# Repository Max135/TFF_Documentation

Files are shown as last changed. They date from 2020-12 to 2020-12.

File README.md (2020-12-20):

# Documentation TFF Smart Fishing Sensor
<p align="center">
    
</p>
Ici se trouve tous les fichiers et documents reliés avec le TFF Smart Fishing Sensor.

## Liens externes
* [Page GitHub du site web](https://github.com/Max135/TFF)
* [Ancien site web](http://tff.sexy)
* [Micro-contrôleur](https://www.adafruit.com/product/4516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)

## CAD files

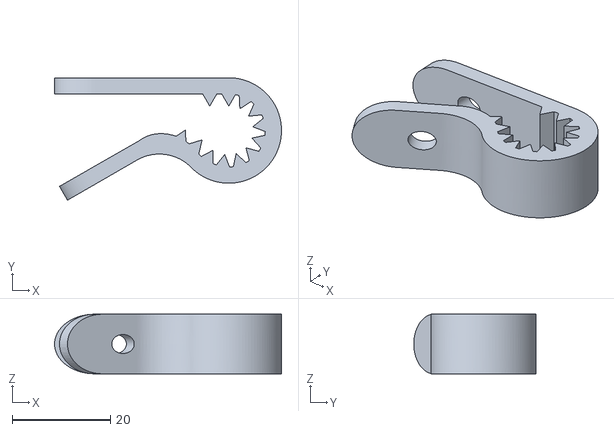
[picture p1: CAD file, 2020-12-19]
Microcontroller/Microcontroller Case/TFF_Clamp.stl
46.2 x 24.9 x 12.1

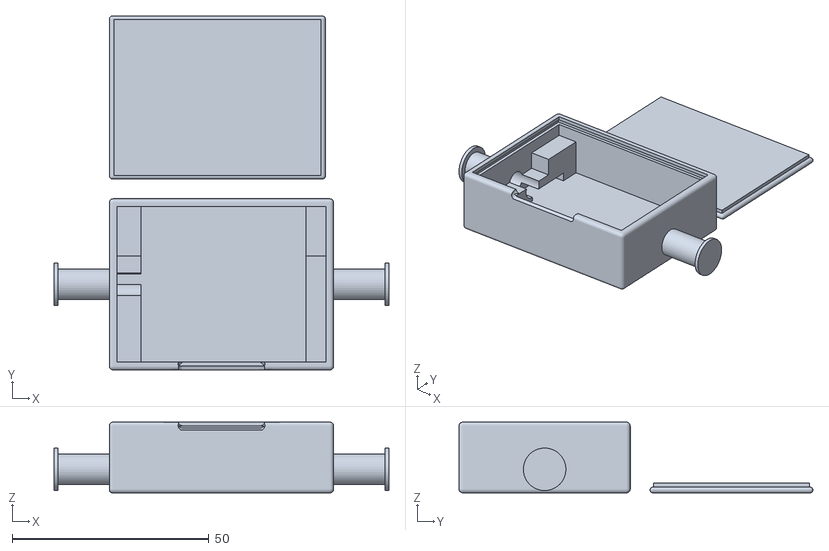
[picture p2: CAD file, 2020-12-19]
Microcontroller/Microcontroller Case/Microcontroller Case v12 + Lid.stl
85.0 x 89.9 x 18.0

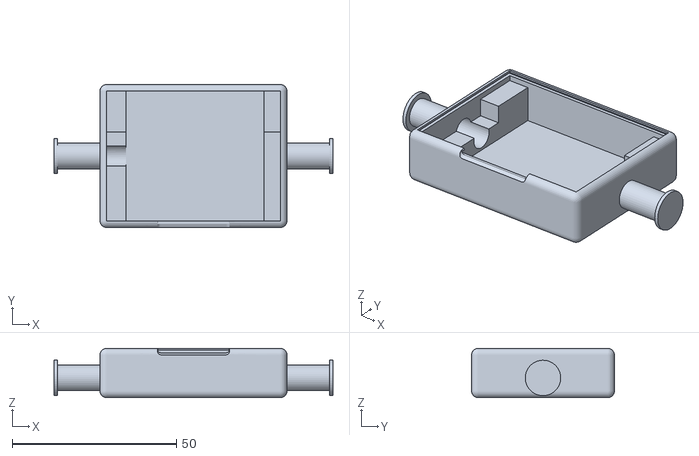
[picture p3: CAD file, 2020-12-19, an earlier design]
Microcontroller/Microcontroller Case/Microcontroller Case v10.stl
85.0 x 43.5 x 15.0

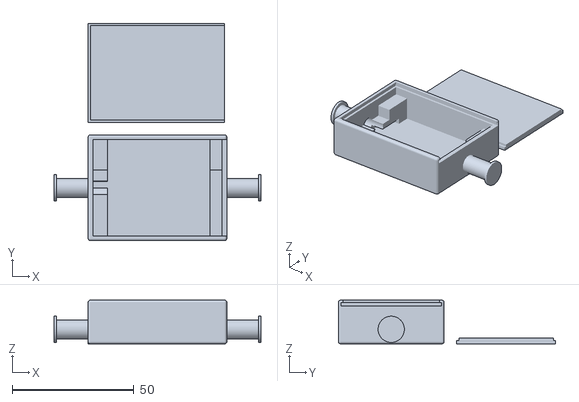
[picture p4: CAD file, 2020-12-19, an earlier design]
Microcontroller/Microcontroller Case/Microcontroller Case v16.stl
85.0 x 89.3 x 18.0

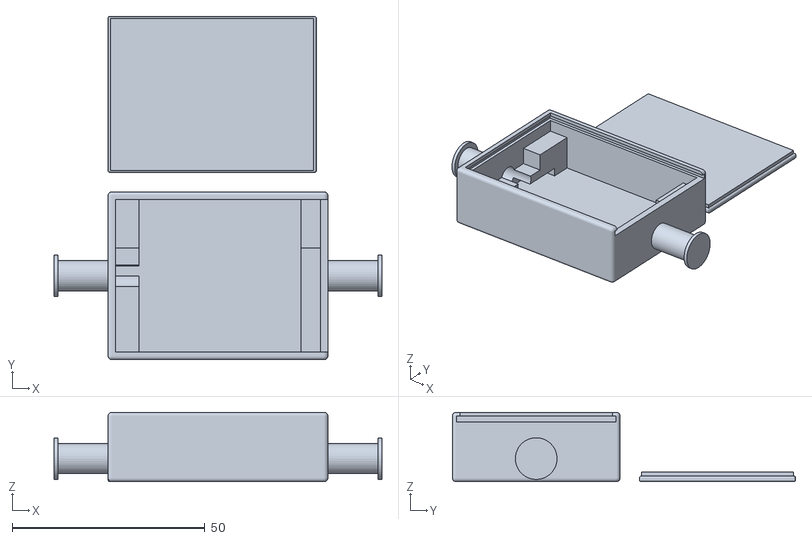
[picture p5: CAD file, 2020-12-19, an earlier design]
Microcontroller/Microcontroller Case/Microcontroller Case v14.stl
85.0 x 89.0 x 18.0

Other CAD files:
Microcontroller/Microcontroller Case/Microcontroller Case v18.stl
Microcontroller/Microcontroller Case/Microcontroller Case v17.stl

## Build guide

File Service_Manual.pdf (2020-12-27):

# Three Fishermen Friends

## Cégep de Sorel-Tracy

# Manuel de service client

## TFF Smart Fishing sensor™

Dernière modification: 19 Décembre 2020

Par: Mickael Salvas, Xavier Loiselle et Maxime Desmarais

Ce document a pour but d’expliquer les détails plus techniques du projet sous trois parties: soit le micro contrôleur, l’application mobile et le site web. Pour tous les documents qui ne se trouve pas dans celui-ci veuillez visiter le GitHub de documentation avec le lien suivant: https://github.com/Max135/TFF_Documentation

## Table des matières

## Three Fishermen Friends ______________________________1

### Manuel de Service Client ________________________________________1

TFF Smart Fishing Sensor™______________________________________________1

### Matériel ________________________________________________________3

Boîtier__________________________________________________________________3 Design du Boitier________________________________________________________3 Composantes Utilisés ___________________________________________________4 Algorithme Micro Contrôleur______________________________________________4 Diagramme Fonctionnel Micro Contrôleur__________________________________5

### Application Mobile ______________________________________________6

Fonctionnement_________________________________________________________6 Diagramme Fonctionnel Application_______________________________________7

### Site Web _______________________________________________________8

Fonctionnement_________________________________________________________8 Diagramme Fonctionnel Site______________________________________________9 Algorithme Hotspot_____________________________________________________10

### Debug ________________________________________________________10

Micro Contrôleur Bricked _______________________________________________10 Aucune Détection de Touches ___________________________________________11

### DIY___________________________________________________________11

## Matériel

## Boîtier

Le boîtier du micro contrôleur et de la batterie a été conçu avec Fusion360.

Le trancheur utilisé pour imprimer le boitier est Ultimaker Cura avec les paramètres suivant:

- Layer height: 0.12mm
- Infill: 100%
- Support: On
- Adhesion: On
L’imprimante utilisée pour imprimer le boitier est une Creality Ender 3 Pro avec du filament PLA noir avec les paramètres suivant:
- Extruder temperature: 200°C
- Bed temperature: 60°C

## Design du boitier

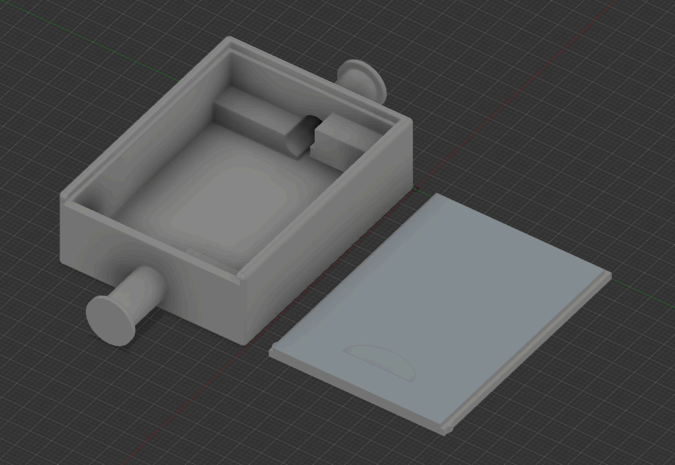
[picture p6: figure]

## Composantes utilisés

Le micro contrôleur utilisé est un Adafruit Feather nRF52840 Sense avec un processeur Nordic nRF52840 Bluetooth LE processor. Le contrôleur comprend les composante suivantes:

- Accéléromètre et gyroscope LSM6DS33
- BME 280
- Microphone PDM
- Détecteur d'humidité SHT
- Capteur de proximité, couleur, lumière et geste APDS9960

De plus, un capteur de vibration Adafruit Industries LLC 1766 (fast) est utilisé.

Le capteur de vibration est connecté au micro contrôleur grâce au pin 10 et 13 de celui-ci.

Le tout est alimenté par une batterie li-po 503035 500mAh.

## Algorithme micro contrôleur

- Le micro contrôleur tente de se connecter à un appareil grâce au Bluetooth
- Une fois une connection établie, le micro contrôleur lit les données de ses sensors à un intervalle de temps donné (actuellement au 5 secondes)
- Le micro contrôleur envoie les données recueillies à l’appareil mobile connecté
- Si une vibration ou une grande accélération est détectée, le micro contrôleur envoi un signal à l'appareil connecté

## Diagramme Fonctionnel micro contrôleur

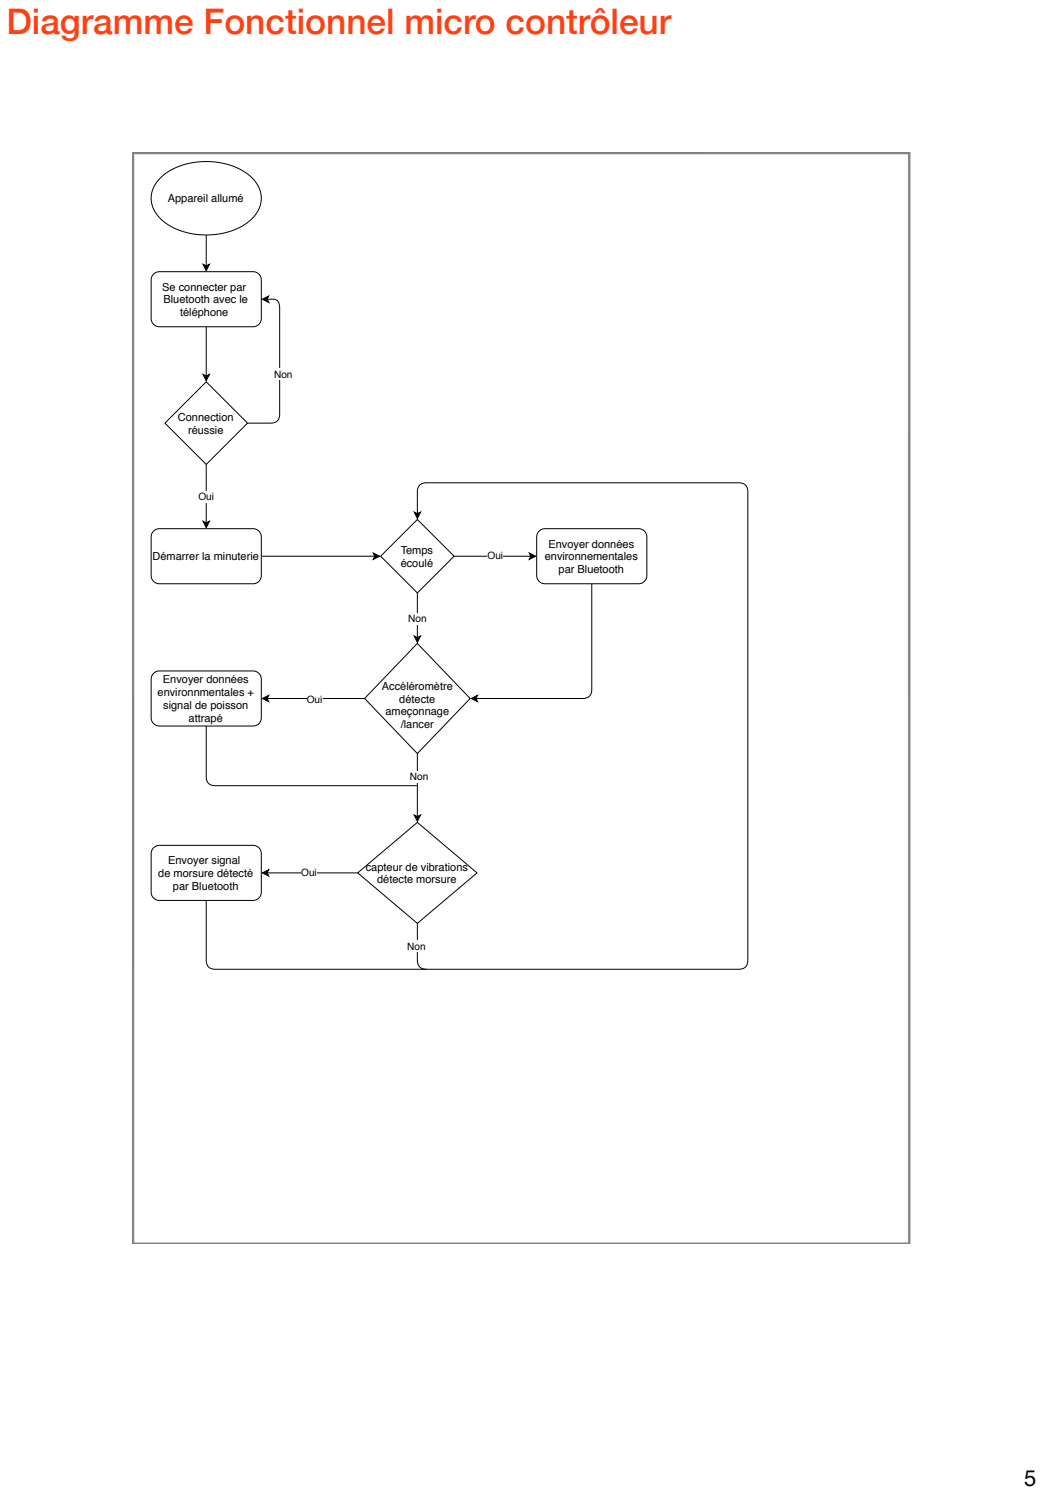
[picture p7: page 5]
Oui; Non; Accéléromètre détecte ameçonnage /lancer; Connection réussie; Démarrer la minuterie; Temps écoulé; Envoyer données environnementales par Bluetooth; Appareil allumé

Se connecter par
Bluetooth avec le
téléphone

Envoyer données
environnmentales +
signal de poisson
attrapé

Envoyer signal
de morsure détecté
par Bluetooth

capteur de vibrations
détecte morsure

## Application mobile

Voici la section consacrée à l’application mobile, incluant son fonctionnement et son diagramme fonctionnel.

## Fonctionnement

- Pour le bon fonctionnement de l’application, il faut que l’application aie accès au Bluetooth, au données GPS, ainsi qu’à l’appareil photo.
- L’application fonctionne en se connectant avec un utilisateur créé sur notre site web (anciennement tff.sexy), en faisant une requête sur notre serveur web pour vérifier l’authentification.
- Lorsque l’utilisateur va se connecter, l’application mobile va faire une requête sur notre serveur web pour obtenir les données de vent selon la position géo-localisée du cellulaire.
- Après la connexion, l’application va commencer à chercher les appareils étant rattachés à un certain UUID (spécifié dans le code de l’application mobile ainsi que le code du micro contrôleur).
- Lorsque l’application va trouver un appareil, elle va tout de suite s’y connecter et commencer à écouter pour recevoir les données de l’appareil connecté.
- Par après, l’application mobile va afficher les données qu’elles va recevoir du micro contrôleur dans les différentes pages (Données météo / Données pêche).
- Ensuite, lorsque l’utilisateur commence un voyage de pêche, l’application mobile envoie une requête à notre serveur web pour lui indiquer le commencement du voyage, et obtenir son identifiant.
- L’affichage des données de pêche est simplement une incrémentation des données reçues par le micro contrôleur.
- Lorsque l’on ajoute une nouvelle capture, l’application envoie à notre serveur web les informations du poisson, ainsi que la photo (ces données sont optionnelles).
- Lors de la fin d’un voyage de pêche, l’application envoie au serveur les données qu’elle à recueillie (météo, données de pêche).

## Diagramme fonctionnel application

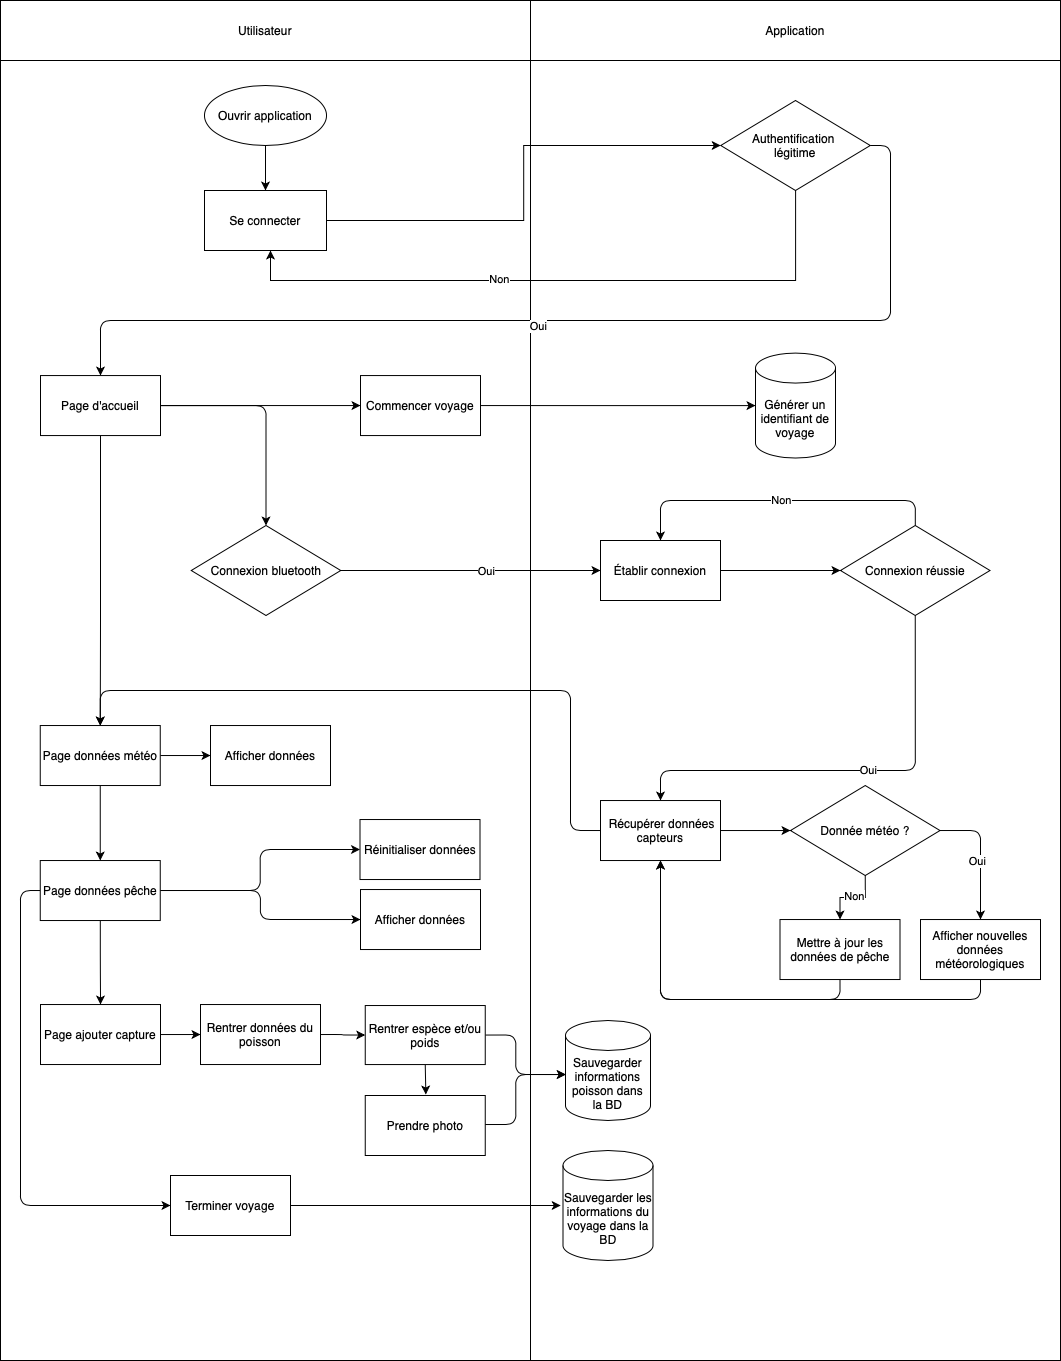
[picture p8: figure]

## Site Web

Le site est fait avec du PHP avec l’aide du framework Zephyrus, Pug est utilisé comme moteur de visualisation et la base de donnée est en mySQL. La carte affichée dans le site est avec Mapbox GL JS (https://docs.mapbox.com/mapbox-gl-js/api/). Tous le code en lien avec le site web peut être trouver dans le GitHub suivant : https://github.com/Max135/TFF

## Fonctionnement

L’utilisateur arrive sur la page index qui donne quelques petites informations sur le produit. Puis avec la navigation à droite, l’utilisateur peut se connecter ou créer un compte.

Après l’authentification avec le courriel et le mot de passe, l’utilisateur est redirigé vers la page avec sa carte qui indique l’emplacement de tous ses point de pêche (Hotspot). L’utilisateur peut appuyer sur un point pour consulter les statistiques et quelques informations du point. Les informations afficher sont le nombre total de poissons attrapés, le nombre total de morsures détectés par le micro contrôleur et le nombre total de ferrages. Une liste de toutes les pressions moyennes pour tous les voyages de pêche dans ce point est affiché. Puis, un icône de vent, avec la vitesse totale de ceux-ci et un icône de caméra seront affiché à l’écran. L’icône de vent apporte sur une page qui indique la moyenne des vitesse de vent ainsi que le minimum et maximum de ceux-ci qui sont affichés avec l'aide d’un graphique. L’icône de caméra redirige vers une page qui affiche tous les photos de poisson prisent avec l’application mobile mentionnée auparavant.

La section permission du site est l’endroit dédié pour faire la gestion du partage des points de pêche, qui ne sont pas partagés par défaut.

La section ami du site permet d’ajouter ou d’enlever des amis. Un ami peut être ajouté avec le courriel de celui-ci. Puis l’utilisateur peut visiter la carte des tous ses amis.

## Diagramme fonctionnel site

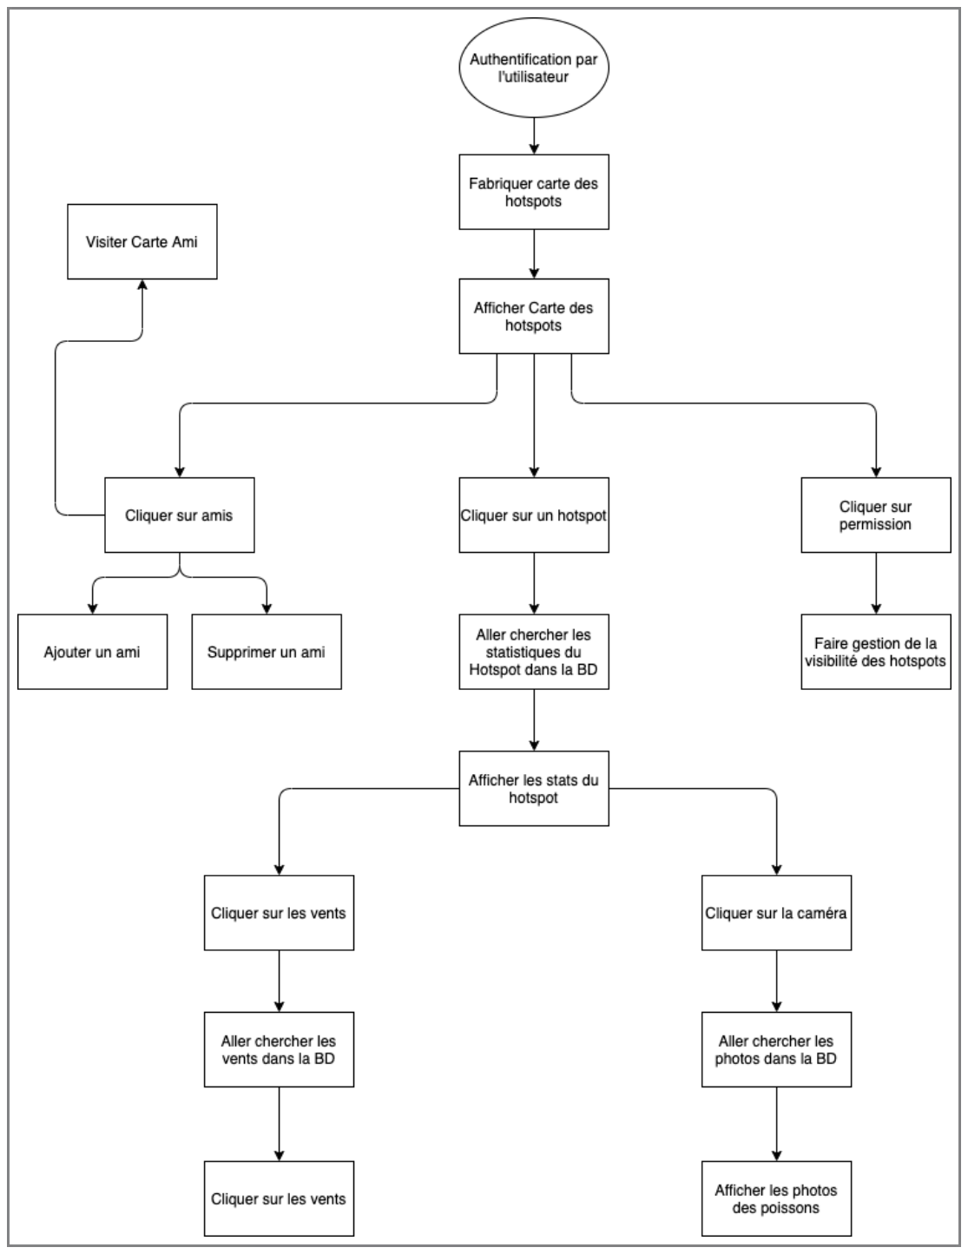
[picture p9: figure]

## Algorithme hotspot

L’algorithme de création de hotspot suit la logique suivante:

- Lors de l’insertion d’un poisson dans la base de donnée (une prise), on vérifie si les coordonnées de la prise sont contenues à l’intérieur d’un hotspot existant.
- Si la prise est contenue dans un hotspot existant, on l’ajoute à ce hotspot, sinon, on vérifie si les coordonnées de deux poissons attrapés par l’utilisateur sont à moins de 200 mètres (Peut être changé facilement)
- Si deux poissons sont assez près l’un de l’autre, on crée un nouveau hotspot qui pourra par la suite contenir d’autres prises, sinon, le poisson est laissé dans le limbo de la base de donnée pour ne plus jamais être revu

## Debug

## Micro contrôleur bricked

Si vous ne recevez plus de signal de votre TFF Smart Fishing sensor™ ou que vous n’êtes plus capable de vous connecter à celui-ci,

1. Retirez le couvercle du boitier
2. Si la DEL multicolore ne change pas de couleur périodiquement suivez les instructions suivante
3. Sortez le micro contrôleur pour pouvoir brancher un câble micro-usb dans son port micro-usb
4. Appuyez rapidement deux fois sur le bouton « Reset », la DEL multicolore devrais maintenant être verte

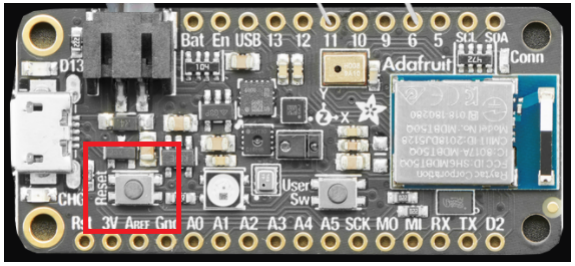
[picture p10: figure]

5. Branchez maintenant le câble micro usb entre votre ordinateur et le micro contrôleur et flashez le avec le code fourni sur git hub avec Arduino IDE
6. Déconnectez le câble micro usb de votre micro contrôleur et rangez le dans le boitier
7. Voilà votre TFF Smart Fishing sensor™ devrais maintenant fonctionner comme neuf!

## Aucune détection de touches

Si votre TFF Smart Fishing sensor™ ne détecte plus les touches alors que vous êtes sûr de les sentir

1. Vérifiez si les fils connectés à votre capteur de vibration ne sont pas coupés
2. Vérifiez si le capteur de vibration est bien connecté aux fils
3. Si votre problème n’est toujours pas réglé, ouvrez le boîtier
4. Vérifiez que les soudures sur le micro contrôleur tiennent toujours
5. Si les soudures sont encore bonnes, remplacez le capteur de vibration, sinon, ressoudez les fils qui ont perdus contact
6. Vous êtes maintenant prêt à retourner pêcher dans vos hotspot favoris!

## DIY

1. Acheter tout le materiel nécessaire
2. Imprimer le boitier
3. Télécharger le code de l’application mobile à partir du Github
4. Installer l’application mobile sur un appareil Apple
5. Connecter la batterie avec le contrôleur
6. Télécharger le script du contrôleur à partir du GitHub
7. Déployer le script sur le micro contrôleur
8. Insérer le contrôleur et la batterie dans le boitier
9. Fixer le boitier sur la canne à pêche
10. Fixer le capteur de vibration plus haut sur la canne à pêche
11. Connecter le capteur dans les pines 10 et 13 du contrôleur
12. Se connecter au contrôleur avec l’application mobile
13. Pêcher !

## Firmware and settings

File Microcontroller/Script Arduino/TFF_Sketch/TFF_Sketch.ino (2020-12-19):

#include <TimedAction.h>
#include <Adafruit_NeoPixel.h>

#include <bluefruit.h>
#include <Adafruit_LittleFS.h>
#include <InternalFileSystem.h>

#include <Adafruit_BMP280.h>
#include <Adafruit_LSM6DS33.h> 
#include <Adafruit_SHT31.h> 
#include <Adafruit_Sensor.h> 

#define RGB_LED_PIN     8
#define LED_COUNT       1
#define PIN_OUT         10
#define PIN_IN          13
#define MIN             -15.5
#define MAX             15.5

#define MAX_TIME_LAST_HOOK 5000

void randomColor();
void setupRGB();
void setupVibrationSensor();
void vibrationDetected();
void getTemperature();
void getPressure();
void getCellphoneData();
void getHumidity();
void getHook();
void getVibration();
void getUserActions();

void sendData();
bool isAccelInTreshold(float, float, float);
void getHookDetected();

BLEDfu  bledfu;  // OTA DFU service
BLEDis  bledis;  // device information
BLEUart bleuart; // uart over ble
BLEBas  blebas;  // battery

Adafruit_BMP280 bmp280; // temperature, barometric pressure
Adafruit_LSM6DS33 lsm6ds33; // accelerometer, gyroscope
Adafruit_SHT31 sht30; // humidity


float temperature, pressure, altitude; 
float accel_x, accel_y, accel_z;
float gyro_x, gyro_y, gyro_z;
float humidity;
String hookDetected;

short sampleBuffer[256]; // buffer to read samples into, each sample is 16-bits 
volatile int samplesRead; // number of samples read

Adafruit_NeoPixel strip(LED_COUNT, RGB_LED_PIN, NEO_GRB + NEO_KHZ800);
boolean vibrationLastClock = false;
boolean hookDetectedLastClock = false;
unsigned long timeLastHook = millis();

TimedAction sendDataThread = TimedAction(5000, sendData);
TimedAction checkHookThread = TimedAction(100, getHookDetected);
TimedAction vibrationThread = TimedAction(1000, getUserActions);
//TimedAction tempThread = TimedAction(5000, getTemperature);
//TimedAction pressureThread = TimedAction(5000, getPressure);
//TimedAction humidityThread = TimedAction(5000, getHumidity);
TimedAction dataThread = TimedAction(10, getCellphoneData);

void setup() {
  Serial.begin(115200);
  setupSensors();
  setupRGB();
  setupVibrationSensor();

  setupBluefruit();
  startBledfu();
  setupBledis();
  startBleuart();
  setupBlebas();
  
  startAdv();

}

void loop() {
  sendDataThread.check();
  checkHookThread.check();
  vibrationThread.check();
//  randomColor();
}

void setupSensors() {
  bmp280.begin();
  lsm6ds33.begin_I2C();
  sht30.begin();
}

void setupBluefruit() {
  Bluefruit.autoConnLed(true);
  Bluefruit.configPrphBandwidth(BANDWIDTH_MAX);
  Bluefruit.begin();
  Bluefruit.setTxPower(4);
  Bluefruit.setName("TFF Smart Fishing");
  
  Bluefruit.Periph.setConnectCallback(connect_callback);
  Bluefruit.Periph.setDisconnectCallback(disconnect_callback);
}

void startBledfu() {
  bledfu.begin();
}

void setupBledis() {
  bledis.setManufacturer("Three Fisherman Friends");
  bledis.setModel("TFF SF-1.0");
  bledis.begin();
}

void startBleuart() {
  bleuart.begin();
}

void setupBlebas() {
  blebas.begin();
  blebas.write(100);
}

void startAdv(void) {
  Bluefruit.Advertising.addFlags(BLE_GAP_ADV_FLAGS_LE_ONLY_GENERAL_DISC_MODE);
  Bluefruit.Advertising.addTxPower();

  Bluefruit.Advertising.addService(bleuart);

  Bluefruit.ScanResponse.addName();

  Bluefruit.Advertising.restartOnDisconnect(true);
  Bluefruit.Advertising.setInterval(32, 244);
  Bluefruit.Advertising.setFastTimeout(30);
  Bluefruit.Advertising.start(0);
}

void sendData() {
  getTemperature();
  getHumidity();
  getPressure();
}

void getUserActions() {
  getHook();
  getVibration();
  randomColor();
}

void getVibration() {
  digitalWrite(PIN_OUT, HIGH);
  if(vibrationLastClock) {
    Serial.println("Vibration detected");
    char buf[128];
    int ret = snprintf(buf, sizeof(buf), "%s", "true <vibration>");
    bleuart.write(buf, ret);
    vibrationLastClock = false;
  }
}

void getHook() {
  Serial.println(hookDetectedLastClock);
  if (hookDetectedLastClock) {
    char buf[128];
    int ret = snprintf(buf, sizeof(buf), "%s", "true <hook>");
    Serial.println(hookDetected);
    bleuart.write(buf, ret);
    hookDetectedLastClock = false;
  }
}

void getHookDetected() {
  if(millis() - timeLastHook > MAX_TIME_LAST_HOOK) {
    sensors_event_t accel;
    sensors_event_t gyro;
    sensors_event_t temp; //temp needed by .getEvent for some reason
    lsm6ds33.getEvent(&accel, &gyro, &temp); 
    accel_x = accel.acceleration.x;
    accel_y = accel.acceleration.y; 
    accel_z = accel.acceleration.z; 
    gyro_x = gyro.gyro.x;
    gyro_y = gyro.gyro.y;
    gyro_z = gyro.gyro.z;
    if (isAccelInTreshold(accel_x, accel_y, accel_z)) {
      Serial.println();
      Serial.print("Throw or hook : ");
      Serial.print("X ");
      Serial.print(accel_x);
      Serial.print(" ");
      Serial.print("Y ");
      Serial.print(accel_y); 
      Serial.print(" ");
      Serial.print("Z ");
      Serial.print(accel_z);
      hookDetectedLastClock = true;
      timeLastHook = millis();
    }
  }
}

bool isAccelInTreshold(float x, float y, float z) {
    return (x < MIN || x > MAX || y < MIN || y > MAX || z < MIN || z > MAX);
}

void getTemperature() {
  char buf[128];
  temperature = bmp280.readTemperature();
  int ret = snprintf(buf, sizeof(buf), "%f%s", temperature, "<temperature>");
  Serial.println();
  Serial.printf("Temperature: %f\n", temperature);
  bleuart.write(buf, ret);
  
}

void getHumidity() {
  char buf[128];
  humidity = sht30.readHumidity();
  int ret = snprintf(buf, sizeof(buf), "%f%s", humidity, "<humidity>");
  Serial.printf("Humidity: %f\n", humidity);
  bleuart.write(buf, ret);
}

void getPressure() {
  char buf[128];
  pressure = bmp280.readPressure() / 1000; // divided by 1000 to convert the pressure from pascals to kiloPascals (kPa)
  int ret = snprintf(buf, sizeof(buf), "%f%s", pressure, "<pressure>");
  Serial.printf("Pressure: %f\n", pressure);
  bleuart.write(buf, ret);
}

void getCellphoneData() {
    while ( bleuart.available() )
    {
      uint8_t ch;
      ch = (uint8_t) bleuart.read();
      Serial.write(ch);
    }
}

void connect_callback(uint16_t conn_handle) {
  // Get the reference to current connection
  BLEConnection* connection = Bluefruit.Connection(conn_handle);

  char central_name[32] = { 0 };
  connection->getPeerName(central_name, sizeof(central_name));

  Serial.print("Connected to ");
  Serial.println(central_name);
}

void disconnect_callback(uint16_t conn_handle, uint8_t reason) {
  (void) conn_handle;
  (void) reason;

  Serial.println();
  Serial.print("Disconnected, reason = 0x"); Serial.println(reason, HEX);
}

void setupVibrationSensor() {
  pinMode(PIN_OUT, OUTPUT);
  attachInterrupt(digitalPinToInterrupt(PIN_IN), vibrationDetected, RISING);
}

void vibrationDetected() {
  if(millis() - timeLastHook > MAX_TIME_LAST_HOOK) {
    vibrationLastClock = true;
  }
}

void setupRGB() {
  strip.begin();
  strip.show(); // Initialize all pixels to 'off'
}

void randomColor() {
  strip.fill(strip.Color(random(20), random(20), random(20)), 0, 1);
  strip.show();
//  delay(500);
}

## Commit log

2020-12-19 Added some files
    [Microcontroller Case v10.stl, Microcontroller Case v12 + Lid.stl, Microcontroller Case v14.stl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]
2020-12-19 Organized files in folders
    [Microcontroller Case v10.stl, Microcontroller Case v12 + Lid.stl, Microcontroller Case v14.stl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]
2020-12-19 Added clamp stl file
    [TFF_Clamp.stl]
